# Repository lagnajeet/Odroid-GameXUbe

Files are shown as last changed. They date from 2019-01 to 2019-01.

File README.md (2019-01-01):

# Ordoid GameXUbe

A gamecude looking console using Odroid XU4 single board computer. 
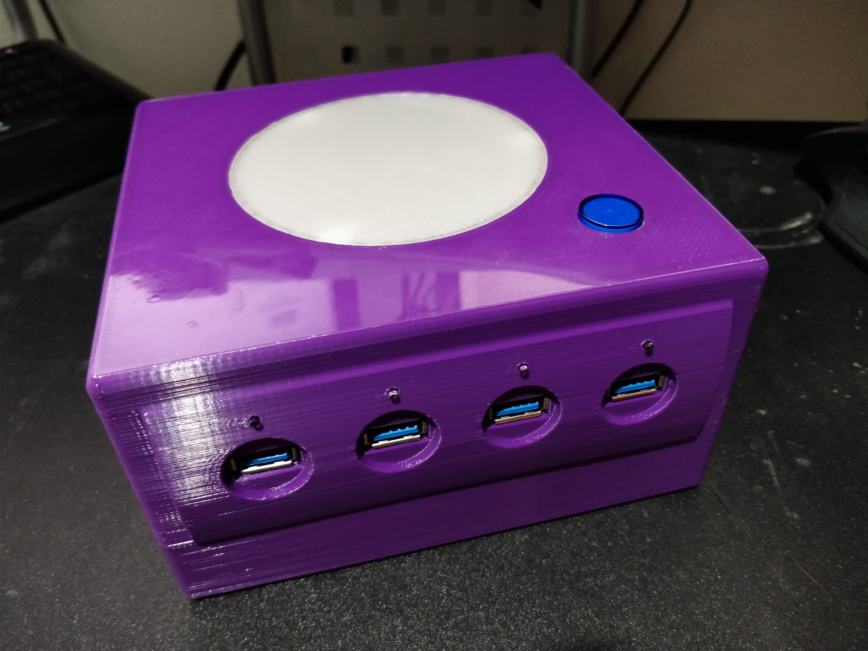
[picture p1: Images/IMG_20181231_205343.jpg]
Odroid GameXUbe case


Below is a demo video of working of the case. It has the retro arena retropie OS installed in the Board. It can be used with other retro OSes like recalbox or batocera.

<a href="http://www.youtube.com/watch?feature=player_embedded&v=xYu04uo0sBY
" target="_blank">Odroid GameXUbe Demo Video</a>

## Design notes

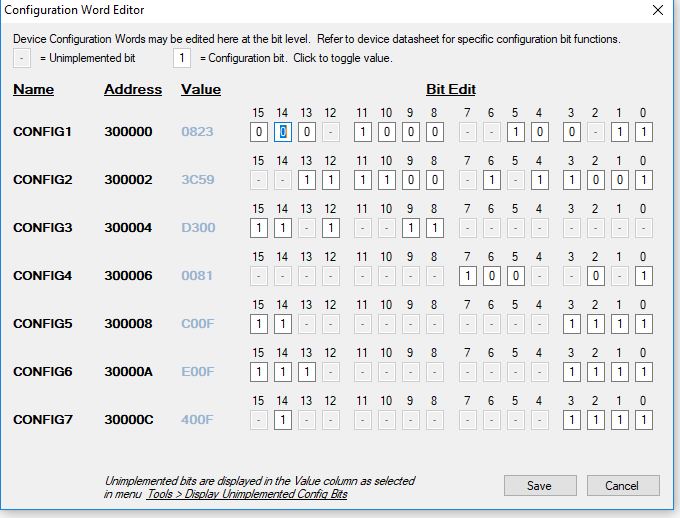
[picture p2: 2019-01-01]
Firmware/configuration bits.JPG

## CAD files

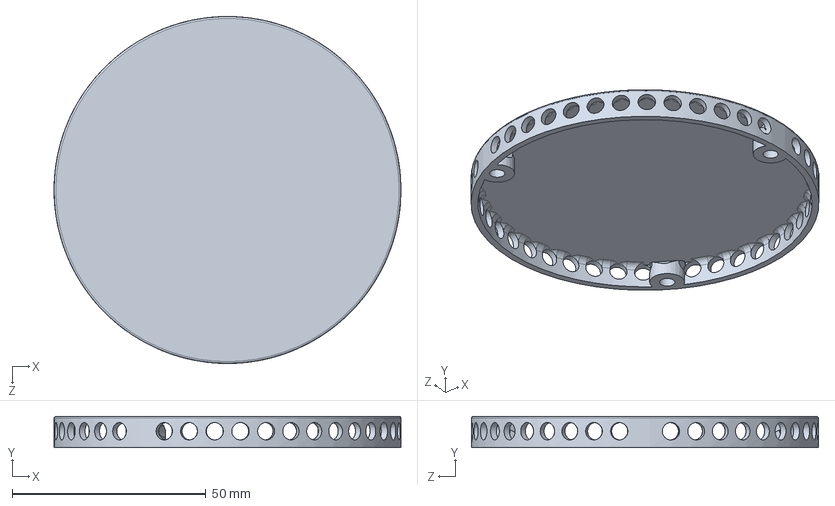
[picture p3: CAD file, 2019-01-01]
Mechanical Design/LED_Decal^Case_assembly.sldprt
89.5 x 8.10 x 89.5 mm

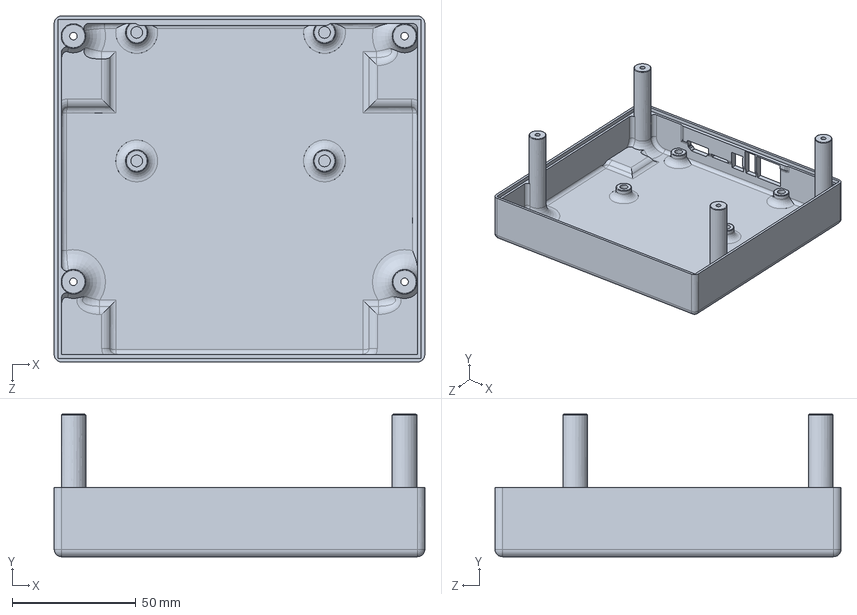
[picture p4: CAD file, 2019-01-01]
Mechanical Design/bottomBox^Case_assembly.sldprt
150.0 x 57.7 x 140.0 mm

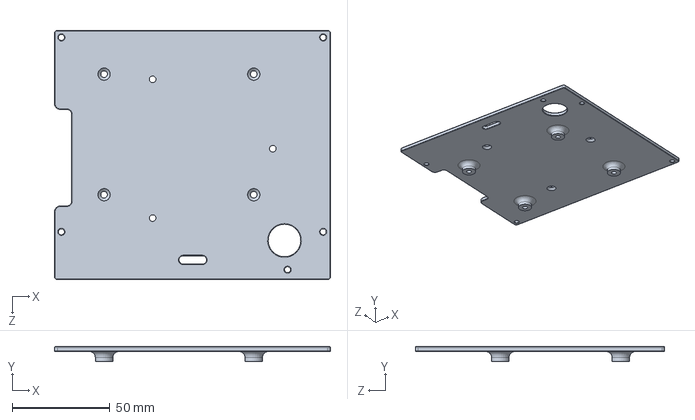
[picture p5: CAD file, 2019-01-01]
Mechanical Design/supportPlate_Backup.SLDPRT
141.3 x 7.50 x 127.6 mm

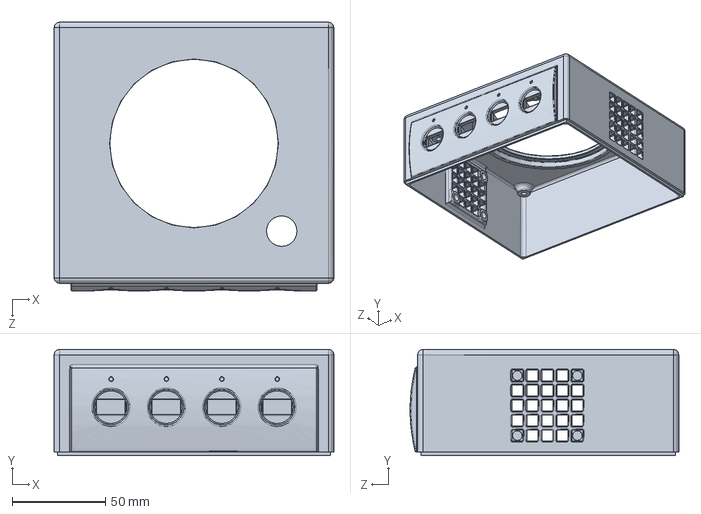
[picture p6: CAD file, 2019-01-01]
Mechanical Design/Top.SLDPRT
150.0 x 57.0 x 144.0 mm

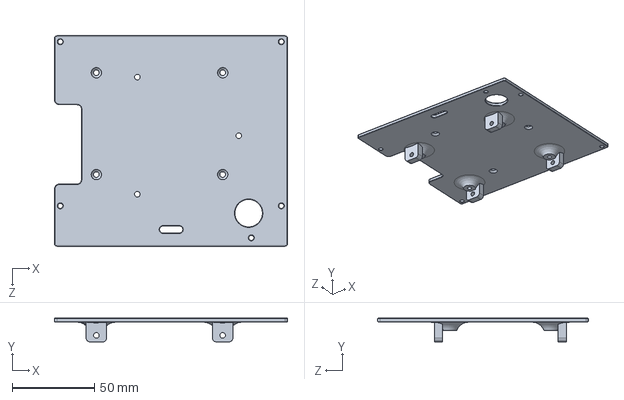
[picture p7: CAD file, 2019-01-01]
Mechanical Design/supportPlate.SLDPRT
141.3 x 14.5 x 127.6 mm

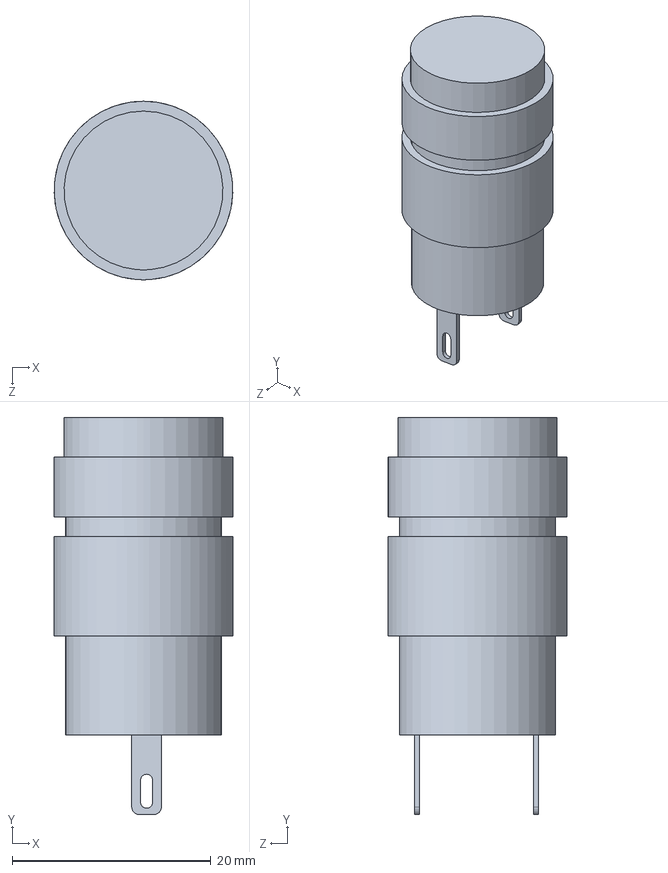
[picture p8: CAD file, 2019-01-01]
Mechanical Design/push_button.SLDPRT
18.0 x 40.0 x 18.0 mm

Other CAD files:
Mechanical Design/3dPrint/LED_Decal.STL
Mechanical Design/3dPrint/bottomBox.STL
Mechanical Design/3dPrint/supportPlate.STL

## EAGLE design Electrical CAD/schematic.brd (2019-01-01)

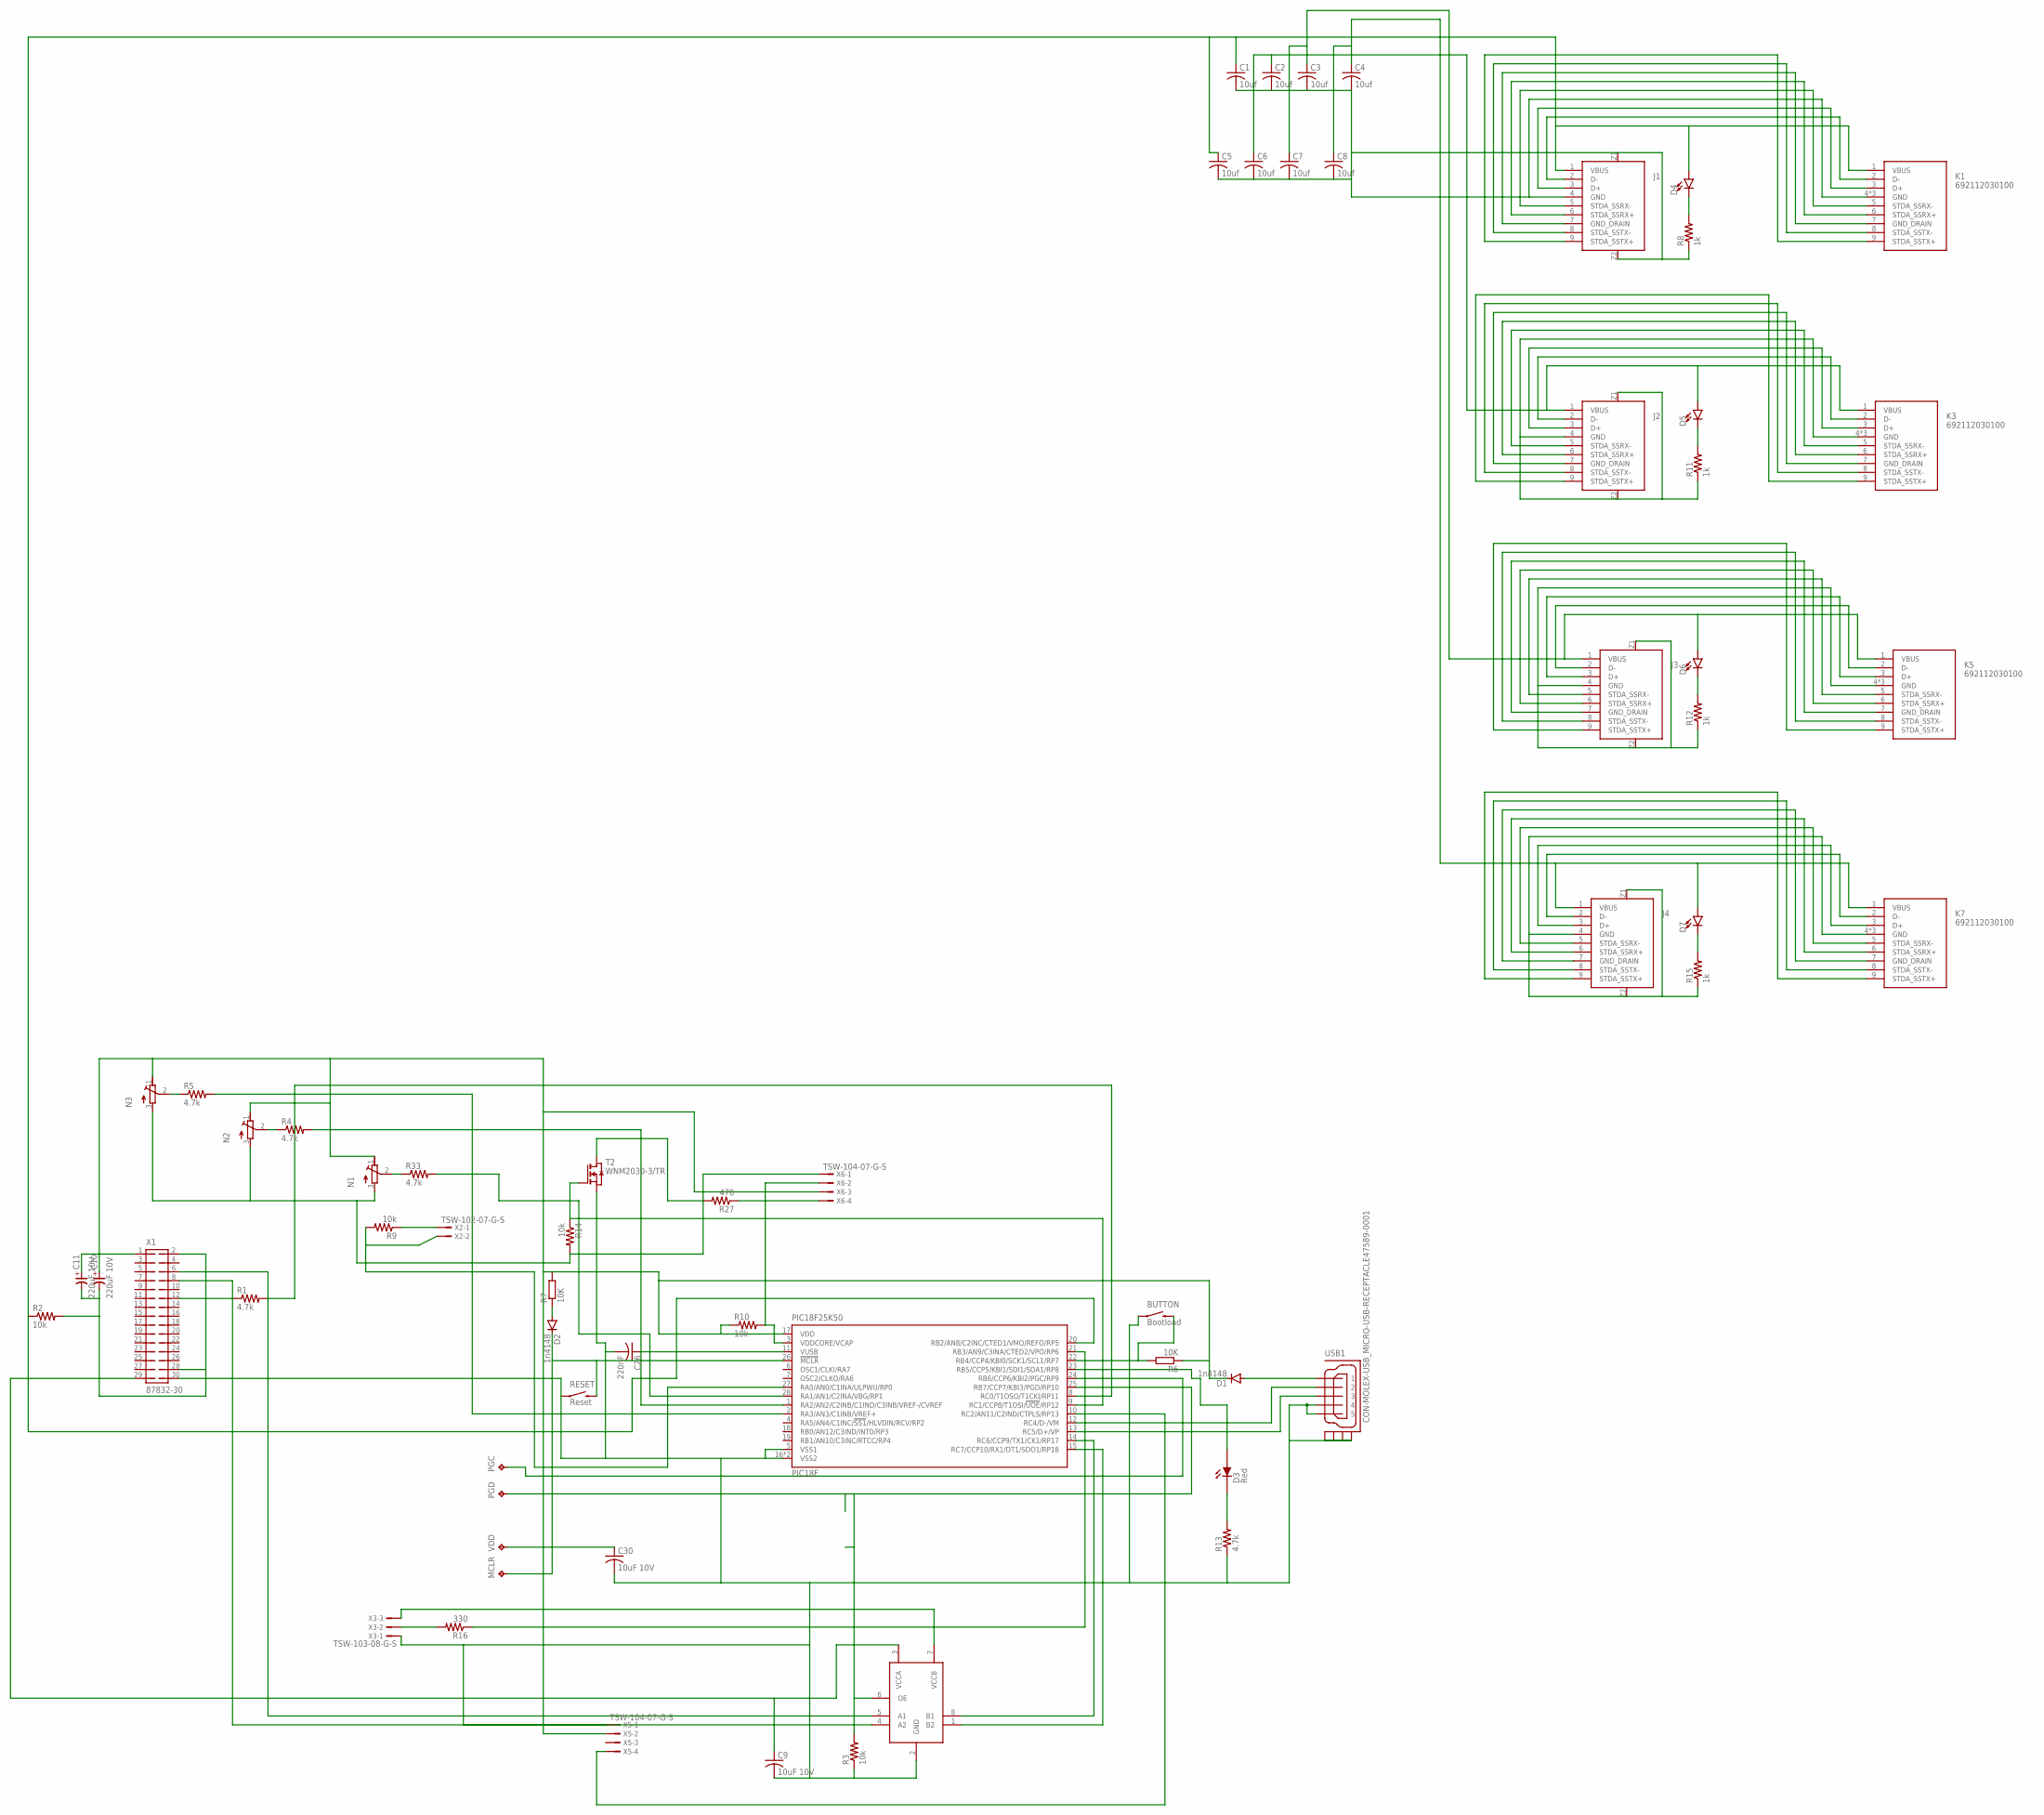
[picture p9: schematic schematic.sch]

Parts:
BUTTON: Bootload; BEAGLEBONE_BLUE_SPARKFUN-ELECTROMECHANICAL_TACTILE_SWITCH_S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
C1, C2, C3, C4, C5, C6, C7, C8: 10uf; C0402
C9, C30: 10uF 10V; ADAFRUIT_C0402
C10, C11: 220uF 10V; 3528-TE-B
C26: 220nF; ADAFRUIT_C0402
D1, D2: 1n4148; SPARKFUN-DISCRETESEMI_SOD-123
D3: Red; M-PAD-2.1_0603P
D4, D5, D6, D7: LED-3MM-NO_SILK; LED_3MM-NS
J1, J2, J3, J4: 692121430000
K1, K3, K5, K7: 692112030100
MCLR: TESTPAD_TPTP15SQ; TESTPAD_TP15SQ
N1, N2, N3: R-TRIMM3314J; RTRIM3314J
PGC: TESTPAD_TPTP15SQ; TESTPAD_TP15SQ
PGD: TESTPAD_TPTP15SQ; TESTPAD_TP15SQ
PIC18F25K50: PIC18F; MICROCHIP_QFN28-ML_6X6MM
R1, R4, R5, R13, R33: 4.7k; ADAFRUIT_R0402
R2, R9: 10k; ADAFRUIT_R0402
R3, R10, R14: 10k; R0402
R6, R7: 10K; RCL_R0402
R8, R11, R12, R15: 1k; R0402
R16: 330; R0402
R27: 470; R0402
RESET: Reset; BEAGLEBONE_BLUE_SPARKFUN-ELECTROMECHANICAL_TACTILE_SWITCH_S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
T2: WNM2030-3/TR; SOT723
U1: TXB0102DCUR; VSSOP8
USB1: CON-MOLEX-USB_MICRO-USB-RECEPTACLE47589-0001; CON-MOLEX-USB_47589-0001
VDD: TESTPAD_TPTP15SQ; TESTPAD_TP15SQ
X1: 87832-30
X2: TSW-102-07-G-S; TSW-102-XX-G-S
X3: TSW-103-08-G-S; TSW-103-XX-G-S
X5, X6: TSW-104-07-G-S; TSW-104-XX-G-S

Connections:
GND: BUTTON.1, BUTTON.2 (1), C1.2, C2.2, C3.2, C4.2, C5.2, C6.2, C7.2, C8.2, C9.2, C10.-, C11.-, C26.2, C30.2, J1.4 (GND), J1.Z1, J1.Z2, J2.4 (GND), J2.Z1, J2.Z2, J3.4 (GND), J3.Z1, J3.Z2, J4.4 (GND), J4.Z1, J4.Z2, K1.4 (GND), K1.Z1 (GND), K1.Z2 (GND), K3.4 (GND), K3.Z1 (GND), K3.Z2 (GND), K5.4 (GND), K5.Z1 (GND), K5.Z2 (GND), K7.4 (GND), K7.Z1 (GND), K7.Z2 (GND), N1.3 (A), N2.3 (A), N3.3 (A), PIC18F25K50.5 (VSS1), PIC18F25K50.16 (VSS2), PIC18F25K50.EXP (VSS2), R2.2, R3.1, R8.1, R11.1, R12.1, R13.1, R14.2, R15.1, RESET.1, RESET.2 (1), T2.2 (S), U1.2 (GND), USB1.4, USB1.5, USB1.CASING1 (GND1), USB1.CASING2 (GND2), USB1.CASING3 (GND3), USB1.CASING4 (GND4), X1.2, X1.28, X1.30, X3.1, X5.1, X6.1
unnamed: C1.1, C5.1, D4.A, J1.1 (VBUS), K1.1 (VBUS), PIC18F25K50.20 (RB2/AN8/C2INC/CTED1/VMO/REFO/RP5), R2.1
unnamed: C2.1, C6.1, D5.A, J2.1 (VBUS), K3.1 (VBUS)
unnamed: J1.2 (D-), K1.2 (D-)
unnamed: J1.3 (D+), K1.3 (D+)
unnamed: R1.1, X1.12
unnamed: J2.7 (GND_DRAIN), K3.7 (GND_DRAIN)
unnamed: J1.5 (STDA_SSRX-), K1.5 (STDA_SSRX-)
unnamed: J1.6 (STDA_SSRX+), K1.6 (STDA_SSRX+)
unnamed: C3.1, C7.1, D6.A, J3.1 (VBUS), K5.1 (VBUS)
unnamed: J1.7 (GND_DRAIN), K1.7 (GND_DRAIN)
unnamed: PIC18F25K50.8 (RC0/T1OSO/T1CKI/RP11), R1.2
unnamed: J1.8 (STDA_SSTX-), K1.8 (STDA_SSTX-)
unnamed: J1.9 (STDA_SSTX+), K1.9 (STDA_SSTX+)
unnamed: J3.7 (GND_DRAIN), K5.7 (GND_DRAIN)
unnamed: C4.1, C8.1, D7.A, J4.1 (VBUS), K7.1 (VBUS)
unnamed: C9.1, U1.3 (VCCA), X1.29
unnamed: J4.7 (GND_DRAIN), K7.7 (GND_DRAIN)
unnamed: PIC18F25K50.15 (RC7/CCP10/RX1/DT1/SDO1/RP18), U1.1 (B2)
unnamed: PIC18F25K50.28 (RA1/AN1/C2INA/VBG/RP1), R33.2
unnamed: PIC18F25K50.14 (RC6/CCP9/TX1/CK1/RP17), U1.8 (B1)
unnamed: U1.5 (A1), X1.6
unnamed: U1.4 (A2), X1.8
unnamed: PGC.TP, PIC18F25K50.24 (RB6/CCP6/KBI2/PGC/RP9)
unnamed: PGD.TP, PIC18F25K50.25 (RB7/CCP7/KBI3/PGD/RP10), R3.2, U1.6 (OE)
unnamed: PIC18F25K50.1 (RA2/AN2/C2INB/C1IND/C3INB/VREF-/CVREF), R4.2
unnamed: D4.K (C), R8.2
unnamed: J2.2 (D-), K3.2 (D-)
unnamed: J2.3 (D+), K3.3 (D+)
unnamed: N2.2 (S), R4.1
unnamed: J3.2 (D-), K5.2 (D-)
unnamed: J3.3 (D+), K5.3 (D+)
unnamed: PIC18F25K50.2 (RA3/AN3/C1INB/VREF+), R5.2
unnamed: J4.2 (D-), K7.2 (D-)
unnamed: J4.3 (D+), K7.3 (D+)
unnamed: D5.K (C), R11.2
unnamed: R27.2, T2.3 (D)
unnamed: D3.1 (D_IN), PIC18F25K50.23 (RB5/CCP5/KBI1/SDI1/SDA1/RP8)
unnamed: D3.2 (D_OUT), R13.2
unnamed: N3.2 (S), R5.1
unnamed: D6.K (C), R12.2
unnamed: D7.K (C), R15.2
unnamed: R16.2, X3.2
unnamed: PIC18F25K50.21 (RB3/AN9/C3INA/CTED2/VPO/RP6), R16.1
unnamed: R9.1, X2.1
unnamed: PIC18F25K50.27 (RA0/AN0/C1INA/ULPWU/RP0), R9.2, X2.2
unnamed: PIC18F25K50.9 (RC1/CCP8/T1OSI/!UOE!/RP12), R14.1, T2.1 (G)
unnamed: D1.A, USB1.1
unnamed: C26.1, PIC18F25K50.11 (VUSB)
unnamed: C10.+, C11.+, C30.1, D1.C, N1.1 (E), N2.1 (E), N3.1 (E), PIC18F25K50.17 (VDD), R6.1, R7.2, R10.1, U1.7 (VCCB), VDD.TP, X1.1, X3.3, X5.2, X6.3
unnamed: BUTTON.3 (2), BUTTON.4 (2), PIC18F25K50.22 (RB4/CCP4/KBI0/SCK1/SCL1/RP7), R6.2
unnamed: D2.A, R7.1
unnamed: D2.C, MCLR.TP, PIC18F25K50.26 (!MCLR), RESET.3 (2), RESET.4 (2)
unnamed: PIC18F25K50.10 (RC2/AN11/C2IND/CTPLS/RP13), X5.4
unnamed: R27.1, X6.4
unnamed: N1.2 (S), R33.1
unnamed: J2.5 (STDA_SSRX-), K3.5 (STDA_SSRX-)
unnamed: J2.6 (STDA_SSRX+), K3.6 (STDA_SSRX+)
unnamed: PIC18F25K50.3 (VDDCORE/VCAP), R10.2, X6.2
unnamed: J3.5 (STDA_SSRX-), K5.5 (STDA_SSRX-)
unnamed: J3.6 (STDA_SSRX+), K5.6 (STDA_SSRX+)
unnamed: J4.5 (STDA_SSRX-), K7.5 (STDA_SSRX-)
unnamed: J4.6 (STDA_SSRX+), K7.6 (STDA_SSRX+)
unnamed: J2.8 (STDA_SSTX-), K3.8 (STDA_SSTX-)
unnamed: J2.9 (STDA_SSTX+), K3.9 (STDA_SSTX+)
unnamed: J3.8 (STDA_SSTX-), K5.8 (STDA_SSTX-)
unnamed: J3.9 (STDA_SSTX+), K5.9 (STDA_SSTX+)
unnamed: J4.8 (STDA_SSTX-), K7.8 (STDA_SSTX-)
unnamed: J4.9 (STDA_SSTX+), K7.9 (STDA_SSTX+)
unnamed: PIC18F25K50.12 (RC4/D-/VM), USB1.2
unnamed: PIC18F25K50.13 (RC5/D+/VP), USB1.3

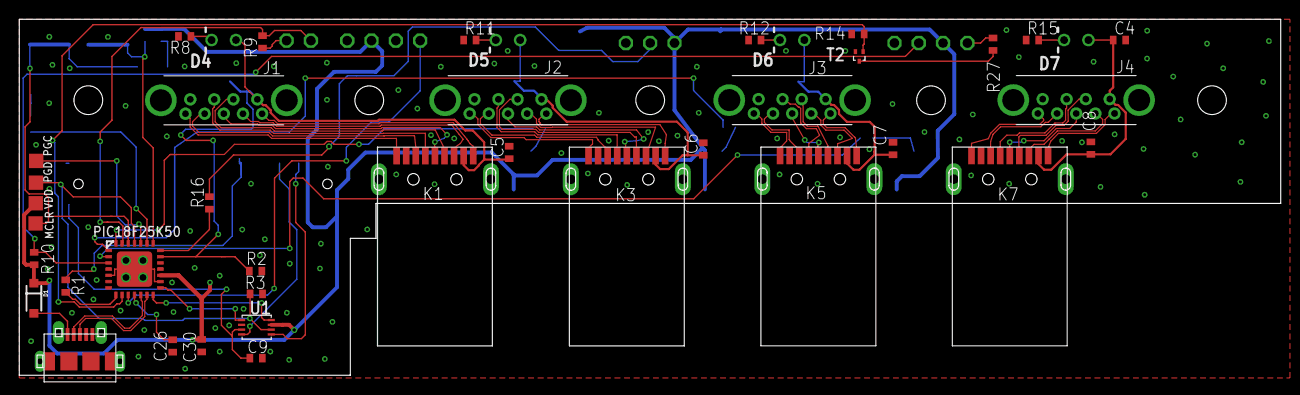
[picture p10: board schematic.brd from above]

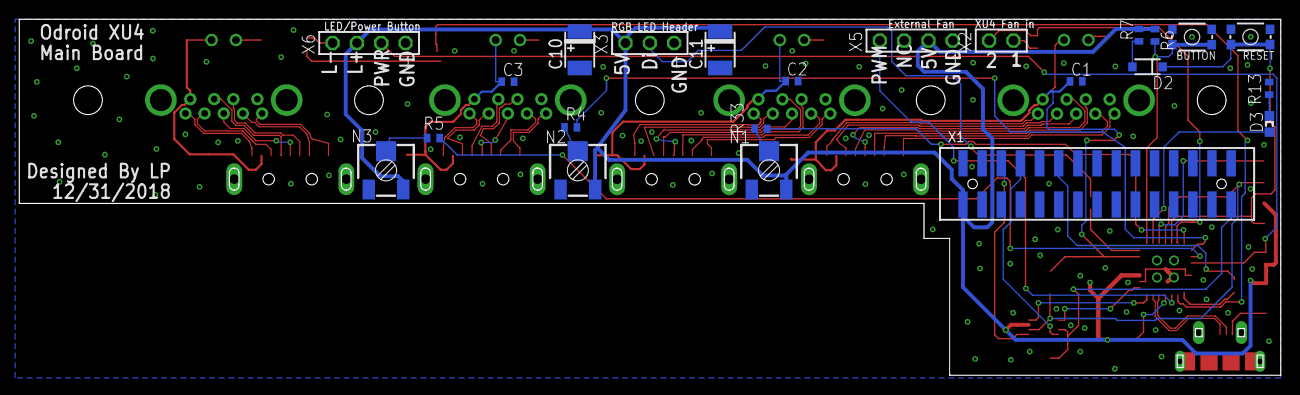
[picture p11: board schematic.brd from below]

Board: 2 copper layers, 131.7 x 37.2 mm, 64 parts (23 on the bottom side), 71 nets.

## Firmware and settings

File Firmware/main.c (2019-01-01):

#define __USB_PIC_PERIF__ 1

#include <18LF25K50.h>
#device ADC=8
#FUSES NOWDT                    //No Watch Dog Timer
#FUSES NOPROTECT                //Code not protected from reading
#FUSES NOBROWNOUT               //No brownout reset
#FUSES NOPUT                    //No Power Up Timer
#FUSES NOCPD                    //No EE protection
#FUSES STVREN                   //Stack full/underflow will cause reset
#FUSES NODEBUG                  //No Debug mode for ICD
#FUSES NOLVP                    //No low voltage prgming, B3(PIC16) or B5(PIC18) used for I/O
#FUSES NOWRT                    //Program memory not write protected
#FUSES NOWRTD                   //Data EEPROM not write protected
#FUSES MCLR                     //Master Clear pin enabled
#FUSES NOXINST                  //Extended set extension and Indexed Addressing mode disabled (Legacy mode)
#FUSES PLL3X, PLLEN, HSH, NOCPUDIV, PRIMARY, NOIESO, NOFCMEN
#use delay(internal=48000000,USB_FULL) 
#use rs232(baud=9600,parity=N,xmit=PIN_C6,rcv=PIN_C7,bits=8)

#DEFINE USB_HID_DEVICE  TRUE //Tells the CCS PIC USB firmware to include HID handling code.
#define USB_EP1_TX_ENABLE  USB_ENABLE_INTERRUPT   //turn on EP1 for IN bulk/interrupt transfers
#define USB_EP1_TX_SIZE    64  //allocate 64 bytes in the hardware for transmission
#define USB_EP1_RX_ENABLE  USB_ENABLE_INTERRUPT   //turn on EP1 for OUT bulk/interrupt transfers
#define USB_EP1_RX_SIZE    64  //allocate 64 bytes in the hardware for reception

#define LOADER_SIZE                 (0x7FF)
#define LOADER_START                (0)
#define LOADER_END                  (LOADER_SIZE)
#define APPLICATION_START           (LOADER_SIZE+1)
#define APPLICATION_END             (getenv("PROGRAM_MEMORY")-1)
#define APPLICATION_ISR             (APPLICATION_START+8)

#ifndef _bootloader
 //in the application, this moves the reset and isr vector out of the bootload
 //space.  it then reserves the loader space from being used by the application.
 #build(reset=APPLICATION_START, interrupt=APPLICATION_ISR)
 #org 0, LOADER_END {}
#endif 

#include <pic18_usb.h>
#include "usb_desc_hid.h"    //USB Configuration and Device descriptors for this UBS device
#include <usb.c> 

#use FAST_IO(ALL) 
#include <WS2812.h> 
#include <WS2812_Effects.c> 

int1 systemup=0;
int1 LEDOFF=0;
unsigned int16 counter1=0;
int pwrButtonPWM=0;
unsigned int16 caseFanPWM=12000;
signed int PWMDirection=1;
// Pin B2 is high if system is on 

#INT_RTCC
void  RTCC_isr(void) 
{
   int i=0;
   if(systemup==0)     //the system is off. do a fade in , fade out of the blue power button
    {       
         if(caseFanPWM>0)
            caseFanPWM--;
         set_pwm1_duty((int16)caseFanPWM);
         set_pwm2_duty((int16) pwrButtonPWM);
         if(pwrButtonPWM==128)
            PWMDirection=-1;
         if(pwrButtonPWM==3)
            PWMDirection=1;
         pwrButtonPWM=pwrButtonPWM+PWMDirection;
         counter1=0;
    }
    else
    {
      LEDOFF=0;
      caseFanPWM=10200;
      set_pwm1_duty((int16)caseFanPWM);
      pwrButtonPWM=0;
      set_pwm2_duty((int16) 0);
    }
}


void main() 
{
  unsigned int8 in_data[65];
  unsigned int8 out_data[65];
  unsigned int idx=0;
  int1 buttonPressed=0;
  char kbChar;
  int8 R,G,B;
  setup_adc_ports(sAN0 | sAN3 | sAN4);
  setup_adc(ADC_CLOCK_INTERNAL | ADC_TAD_MUL_0);
  setup_timer_0(RTCC_INTERNAL|RTCC_DIV_4);      //52.4 ms overflow
  enable_interrupts(INT_RTCC);
  enable_interrupts(GLOBAL);
  setup_timer_2(T2_DIV_BY_16, 106, 1); //142 us overflow, 142 us interrupt
  unsigned int32 commandcounter_before = 65535;
  unsigned int32 commandcounter = 0;
  setup_ccp1(CCP_PWM|CCP_SHUTDOWN_AC_L|CCP_SHUTDOWN_BD_L);
  setup_ccp2(CCP_PWM);
  set_pwm2_duty((int16) 0);
  int i = 0;
  unsigned int value = 0;
  output_high(PIN_B3);
  output_high(PIN_B7);
  output_float(PIN_C0);
  output_low(PIN_C0);
  output_high(PIN_C0);
  delay_ms(1500);
  output_low(PIN_C0);
  //output_float(PIN_C0);
  set_tris_b(0b00000000);
  set_tris_c(0b00000000);
  for (i = 0; i < 65; i++) {
    in_data[i] = 0;
    out_data[i] = 0;
  }
  Strip_Init();
  for (i = 0; i < STRIP_SIZE; i++)
    Strip_setPixelColor(i, 16, 32, 16);
  Strip_Show();
  while (TRUE) 
  {
    output_high(PIN_B7);   
    usb_task();
    if (usb_enumerated()) {
      usb_get_packet(1, in_data, 64);
      commandcounter = in_data[32];
      commandcounter = (commandcounter << 8) | in_data[31];
      commandcounter = (commandcounter << 8) | in_data[30];
      commandcounter = (commandcounter << 8) | in_data[29];
      if (commandcounter_before != commandcounter) {
        for (i = 0; i < 64; i++)
          out_data[i] = in_data[i];
        if (in_data[0] == 1) {
          disable_interrupts(GLOBAL);
          write_eeprom(0, 0x9B);
          reset_cpu();
        } else if (in_data[0] == 2) {
          delay_ms(1);
          reset_cpu();
        } else if (in_data[0] == 3) {
          write_eeprom(0, 0xFF);
        }
        commandcounter_before = commandcounter;
      }
    }
    //putc('*');
    if (!input(PIN_A4)) 
    {
      if(buttonPressed==0)
      {
         putc(128);
         buttonPressed=1;
        output_low(PIN_C0);
         output_high(PIN_C0);
         delay_ms(5000);
         output_low(PIN_C0);
         systemup=0;
      }
    }
    else
    {
      buttonPressed=0;
    }
    

    if(kbhit())
    {

      kbChar=getc();
      
      if(kbChar==5)
      {
         systemup=1;
         idx=1;
      }
      else if(kbChar==4)
      {
         systemup=0;
         idx=0;
         for (i = 0; i < STRIP_SIZE; i++)
                   Strip_setPixelColor(i, 0, 0, 0);
         Strip_Show();         
      }
      else
      {
         if(idx==1)
            R=kbChar;
         else if(idx==2)
            G=kbChar;        
         else if(idx==3)
         {
            b=kbChar;       
            idx=0;
            for (i = 0; i < STRIP_SIZE; i++)
                   Strip_setPixelColor(i, G, R, B);
            Strip_Show();             
         }
         idx++;
      }

    } 
    
    if (input(PIN_B2))  //This pin senses if the system is on or not
    {
      systemup=1;
      LEDOFF=0;
    }
    else
    {
      systemup=0;
      if(LEDOFF==0)
         {
            LEDOFF=1;
            for (i = 0; i < STRIP_SIZE; i++)
                   Strip_setPixelColor(i, 0, 0, 0);
            Strip_Show();  
         }
    }
      //putc('/');
    //{
      //output_low(PIN_C0);
      //output_high(PIN_C0);
      //delay_ms(250);
      //output_low(PIN_C0);
      //output_float(PIN_C0);
      //delay_ms(10000);
      //printf("PIN_A4 is Low");
      //set_pwm2_duty((int16) 200);

    //}
    //else
      //set_pwm2_duty((int16) 0);
    //if (input(PIN_C7)) 
    //  set_pwm2_duty((int16) 0);
    //else
    //  set_pwm2_duty((int16) 200);
    //else
    //   output_low (PIN_C0);

    //TODO: User Code
    //      for(i=0;i<100;i++)
    //      {
    //         set_pwm2_duty((int16)i);
    //         delay_ms (10);
    //      }
    //      for(i=100;i>0;i--)
    //      {
    //         set_pwm2_duty((int16)i);
    //         delay_ms (10);
    //      }
    //      set_adc_channel(4);
    //      delay_us(10);
    //      value = read_adc();
    //if(input(PIN_A1))
    //    set_pwm2_duty((int16)100);
    //else
    //    set_pwm2_duty((int16)0);

    //ColorWipe(strip_Color(255, 0, 0), 50); 
    // ColorWipe(strip_Color(0, 255, 0), 50); 
    // ColorWipe(strip_Color(0, 0, 255), 50); 

    // TheaterChase(Strip_Color(127,127,127), 50); 
    // TheaterChase(Strip_Color(127,0,0), 50); 
    //TheaterChase(Strip_Color(0,127,0), 50); 
    // TheaterChase(Strip_Color(0,0,127), 50); 

    //Rainbow(20); 

    //RainbowCycle(20); 

    //TheaterChaseRainbow(50); 
  }

}

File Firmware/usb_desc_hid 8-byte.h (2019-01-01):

///////////////////////////////////////////////////////////////////////////
///                          usb_desc_hid.h                            ////
////                                                                   ////
//// An example set of device / configuration descriptors for use with ////
//// CCS's HID Demo example (see ex_usb_hid.c)                         ////
////                                                                   ////
///////////////////////////////////////////////////////////////////////////
////                                                                   ////
//// Version History:                                                  ////
////                                                                   ////
//// June 20th, 2005:                                                  ////
////   PIC18Fxx5x initial release                                      ////
////                                                                   ////
//// March 21st, 2005:                                                 ////
////   EP 0x01 and EP 0x81 now use USB_EP1_TX_SIZE and USB_EP1_RX_SIZE ////
////      to define max packet size, to make it easier for dynamically ////
////      changed code.                                                ////
////   EP 0x01 and EP 0x81 will now use 1ms polling interval if using  ////
////      a full speed device.                                         ////
////                                                                   ////
//// May 4th, 2004: Optimization and cleanup.                          ////
////                Some definitions may have changed.                 ////
////                                                                   ////
//// May 6th, 2003: Fixed non-HID descriptors pointing to faulty       ////
////                strings                                            ////
////                                                                   ////
//// August 2nd, 2002: Initial Public Release                          ////
////                                                                   ////
////                                                                   ////
///////////////////////////////////////////////////////////////////////////
////        (C) Copyright 1996,2005 Custom Computer Services           ////
//// This source code may only be used by licensed users of the CCS    ////
//// C compiler.  This source code may only be distributed to other    ////
//// licensed users of the CCS C compiler.  No other use,              ////
//// reproduction or distribution is permitted without written         ////
//// permission.  Derivative programs created using this software      ////
//// in object code form are not restricted in any way.                ////
///////////////////////////////////////////////////////////////////////////

#IFNDEF __USB_DESCRIPTORS__
#DEFINE __USB_DESCRIPTORS__

#include <usb.h>

   //////////////////////////////////////////////////////////////////
   ///
   ///  HID Report.  Tells HID driver how to handle and deal with
   ///  received data.  HID Reports can be extremely complex,
   ///  see HID specifcation for help on writing your own.
   ///
   ///  CCS example uses a vendor specified usage, that sends and
   ///  receives 2 absolute bytes ranging from 0 to 0xFF.
   ///
   //////////////////////////////////////////////////////////////////

   const char USB_CLASS_SPECIFIC_DESC[] = {
      6, 0, 255,    // Usage Page = Vendor Defined
      9, 1,            // Usage = IO device
      0xa1, 1,       // Collection = Application
      0x19, 1,        // Usage minimum
      0x29, 8,        // Usage maximum

      0x15, 0x80,        // Logical minimum (-128)
      0x25, 0x7F,        // Logical maximum (127)

      0x75, 8,        // Report size = 8 (bits)
      0x95, 4,        // Report count = 4 bytes
      0x81, 2,        // Input (Data, Var, Abs)
      0x19, 1,        // Usage minimum
      0x29, 8,        // Usage maximum
      0x75, 8,        // Report size = 8 (bits)
      0x95, 4,        // Report count = 4 bytes
      0x91, 2,        // Output (Data, Var, Abs)
      0xc0            // End Collection
   };

   //if a class has an extra descriptor not part of the config descriptor,
   // this lookup table defines where to look for it in the const
   // USB_CLASS_SPECIFIC_DESC[] array.
   //first element is the config number (if your device has more than one config)
   //second element is which interface number
   //set element to 0xFFFF if this config/interface combo doesn't exist
   const int16 USB_CLASS_SPECIFIC_DESC_LOOKUP[USB_NUM_CONFIGURATIONS][1] =
   {
   //config 1
      //interface 0
         0
   };

   //if a class has an extra descriptor not part of the config descriptor,
   // this lookup table defines the size of that descriptor.
   //first element is the config number (if your device has more than one config)
   //second element is which interface number
   //set element to 0xFFFF if this config/interface combo doesn't exist
   const int16 USB_CLASS_SPECIFIC_DESC_LOOKUP_SIZE[USB_NUM_CONFIGURATIONS][1] =
   {
   //config 1
      //interface 0
         32
   };
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

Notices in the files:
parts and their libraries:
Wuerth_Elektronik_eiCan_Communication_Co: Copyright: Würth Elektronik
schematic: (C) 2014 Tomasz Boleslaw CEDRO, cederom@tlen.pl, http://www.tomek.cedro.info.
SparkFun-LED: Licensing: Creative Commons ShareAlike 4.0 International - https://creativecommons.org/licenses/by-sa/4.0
